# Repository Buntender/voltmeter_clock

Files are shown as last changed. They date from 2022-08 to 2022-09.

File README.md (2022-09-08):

# TimeCube

## 材料

esp8266开发板、5v电压表（6C2型）、电阻、杜邦线、Micro USB延长线、绝缘胶带、胶水、角码、螺丝螺母

螺丝刀 手钻 电烙铁

<div align=center>
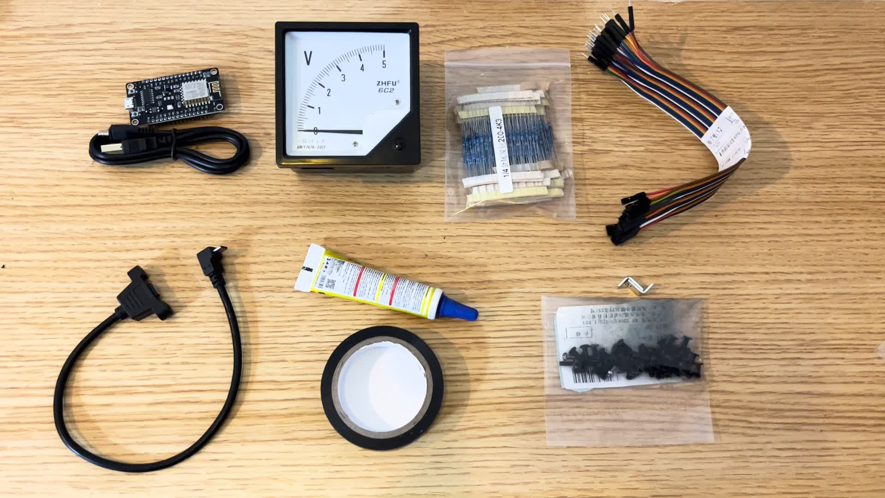
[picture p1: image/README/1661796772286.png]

</div>

## 获取网络时间

配网部分参考了[https://github.com/yuan910715/Esp8266_NTP_Clock_Weather](https://github.com/yuan910715/Esp8266_NTP_Clock_Weather)

开机后首先进入STA模式，通过wificonnect.h中的WIFI_STA,WIFI_PWD连接wifi，连接失败则进入AP模式，用电脑连接热点TimeCube，访问[http://192.168.4.1](http://192.168.4.1/)即可配网。联网成功后通过NTP获取时间。

烧写timetest即可从网络获取时间并经串口发出。

<div align=center>
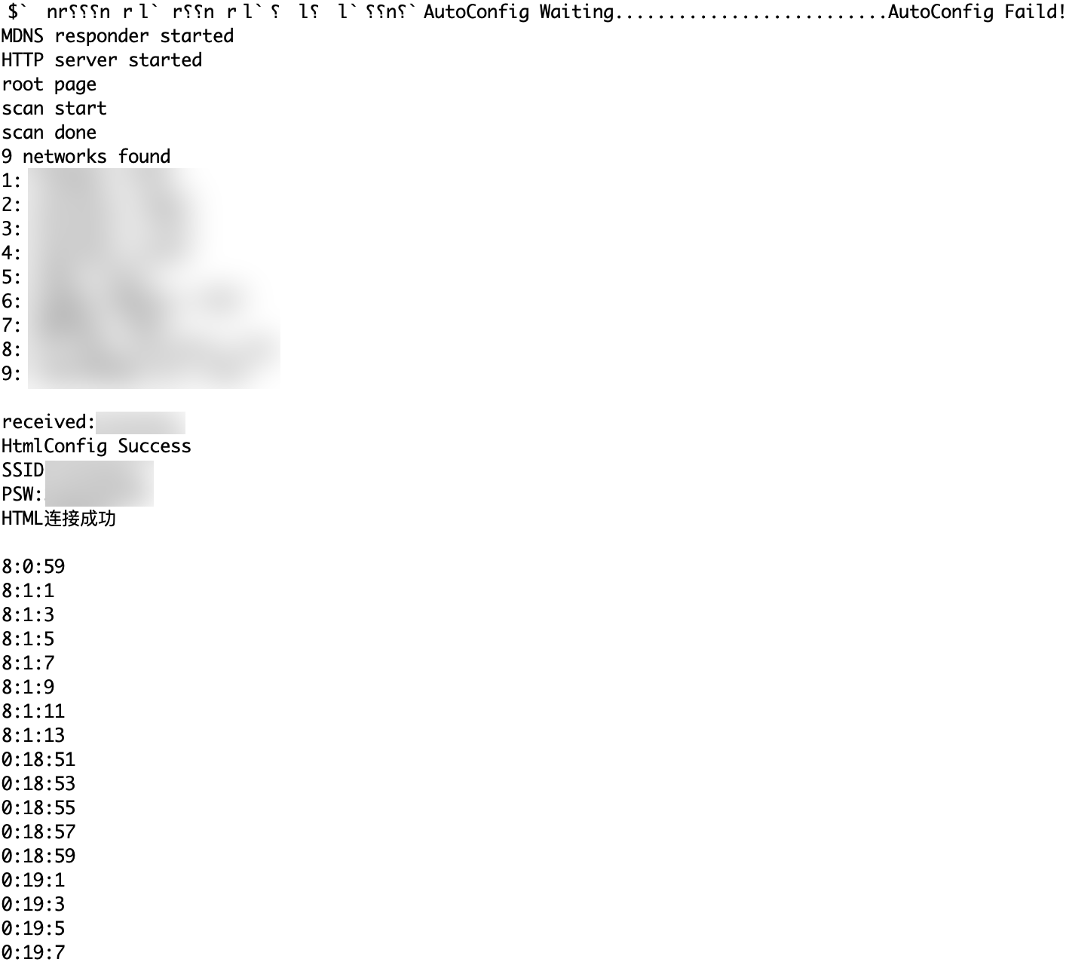
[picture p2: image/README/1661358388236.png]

</div>

可以注意到，设置NTP服务器后，程序会在后台同步时间（如不能同步可以在configTime更换其他国内NTP服务器地址）。

## PWM控制电压表

选择具有PWM输出功能的GPIO口，连接电压表，调整metertest中的METER引脚为相应端口并烧入，可以看到指针匀速划过表盘，但不能划过整个表盘，这是因为ESP8266的工作电压是3.3v，小于电压表的最大值。

<div align=center>
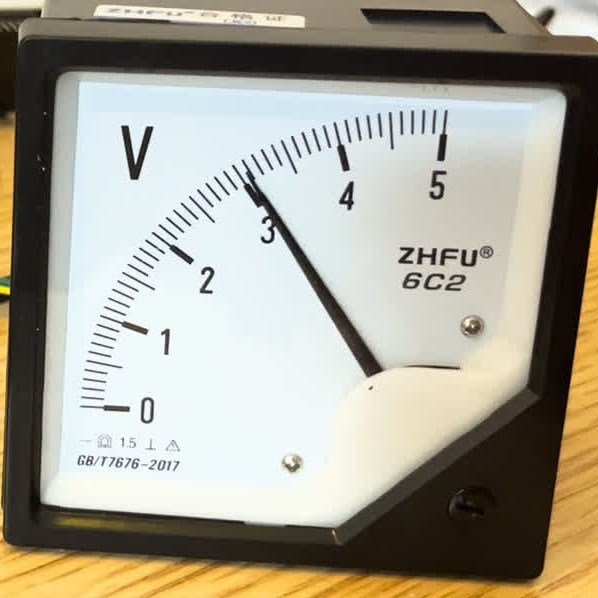
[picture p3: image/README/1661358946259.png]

</div>

拆开电压表后可以看到电压表的结构为表头串联3.3k电阻，则调整量程至3.3v所需的电阻大小为

<div align=center>
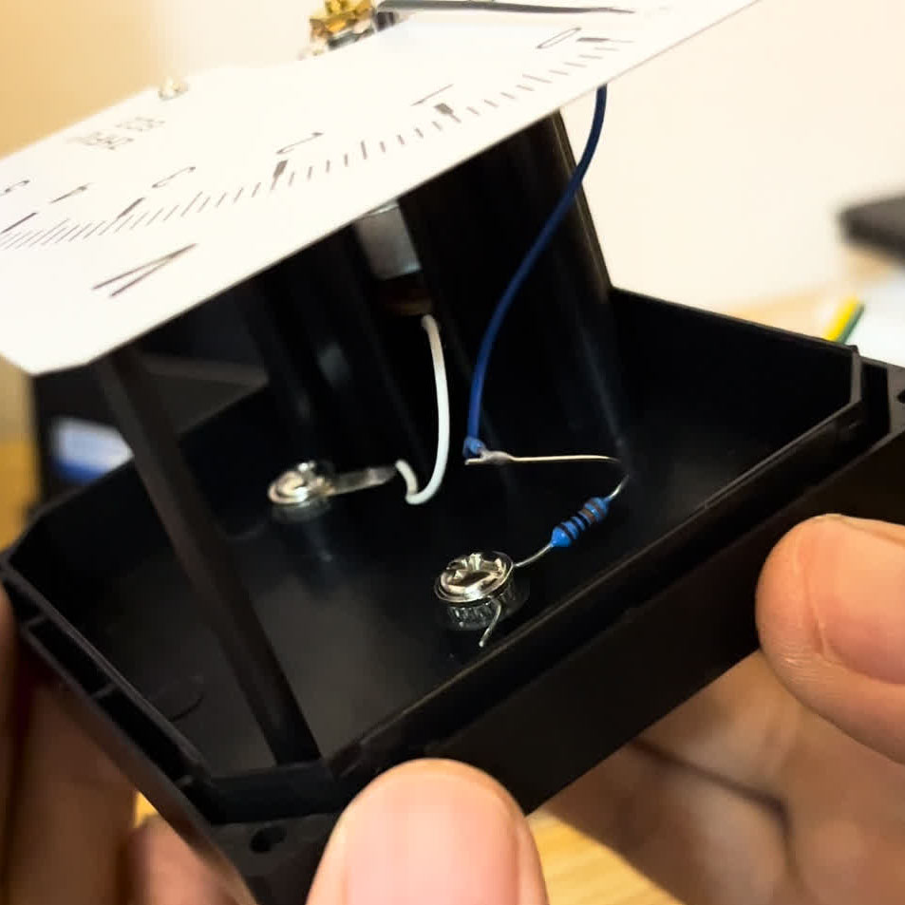
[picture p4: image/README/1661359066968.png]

</div>

$$
\frac{3.3k\Omega}{5v}\times 3.3v\approx2.2k\Omega
$$

为保证指针可以达到满偏（如超过可以在程序中调整最大电压），这里选择阻值为2k的电阻。

<div align=center>
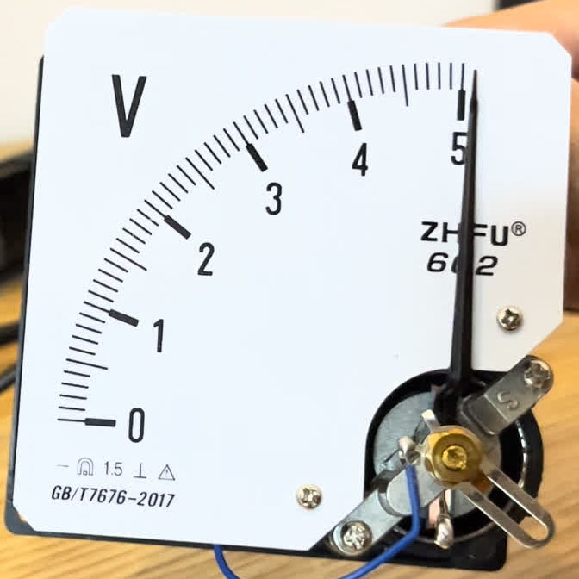
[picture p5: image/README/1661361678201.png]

</div>

最后在表盘黏贴新的刻度即完成了电流表的改装，表盘的设计可以参考panel.ai(panel.png)其中红色的部分需要裁去。

<div align=center>

</div>

## 程序实现

表头时钟TimeCube程序是基于timetest与metertest实现的（如果在ntptest与metertest中调整了参数需要拷贝至TimeCube中），为增强可用性做了一些修改。

* 为防止指针突然运动，在惯性的作用下超出量程打弯指针，也是为了运行中的美观，程序不应突然改变电压。常规走时时，通过循环与延时逐渐改变；归零时（从11点59分到0点）先将电压降为0让指针加速回落，再在指针即将归零前升高电压令指针减速。停止部分的参数和电压表有关，需自行调整，手机的慢动作摄影可以帮助确认减速的时机。

<div align=center>

</div>

* SSID和密码保存在EEPROM中，手动配网时更新保存的密码，重启后不需要重新配网。这一部分参考了[https://blog.csdn.net/qq_31878883/article/details/121452667](https://blog.csdn.net/qq_31878883/article/details/121452667https://blog.csdn.net/qq_31878883/article/details/121452667)
* NTP同步在后台运行，通过系统时间的大小判断是否同步成功（同步后时间在2020年后）。若当前时间正确，可在同步前先减去1.5768e9秒（50年），再判断系统时间。
* 配网时扫描指针。
* 为节省电能，时钟每六小时连接一次网络，通过WiFi.forceSleepBegin和WiFi.forceSleepWake实现。若连续7天未同步成功则重启。

## 组装

在背板上打孔固定micro usb延长线与esp8266开发板（开发板是纵向安放的，安装时用到了角码）

<div align=center>
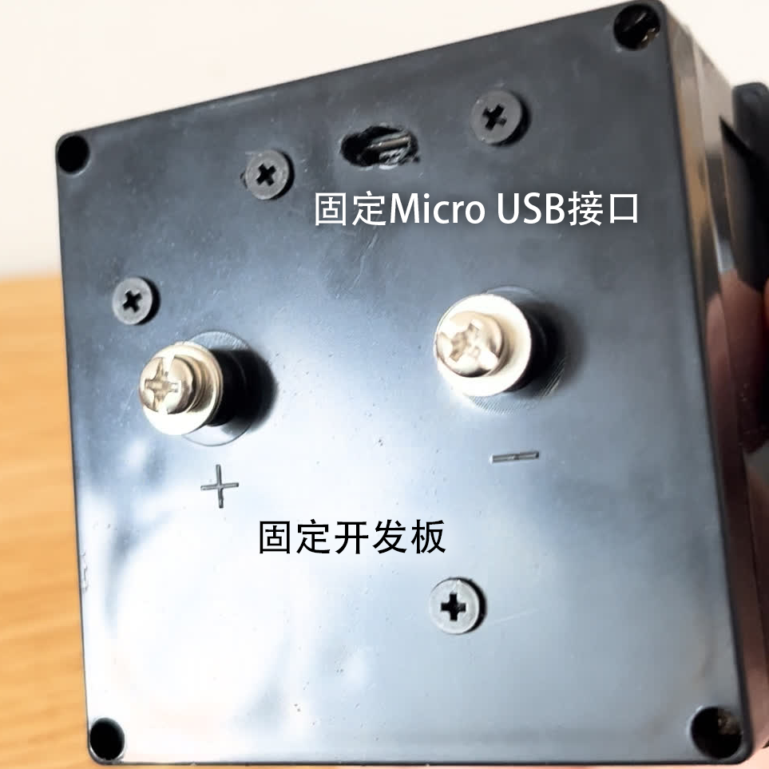
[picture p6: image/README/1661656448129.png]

</div>

分别从接线柱和表头引线用于供电和指示

<div align=center>
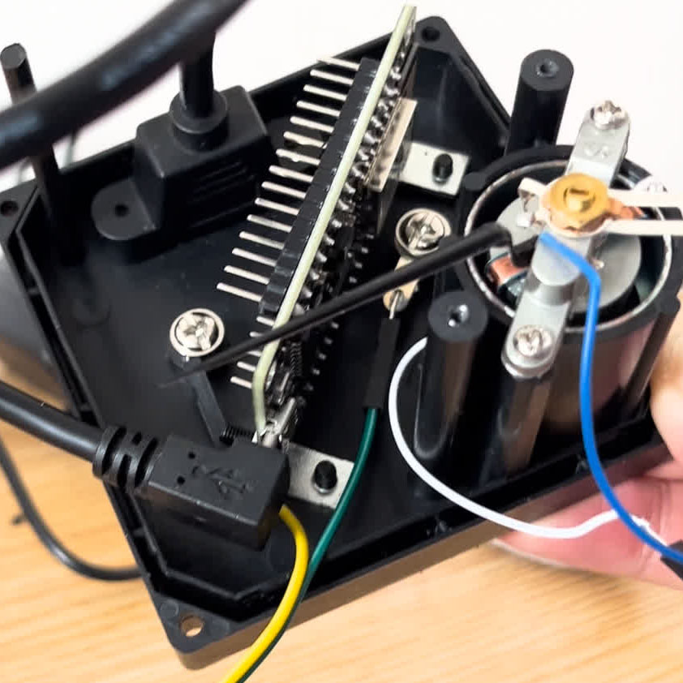
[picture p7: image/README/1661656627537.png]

</div>

完成连线的效果如下，需注意用绝缘胶带覆盖裸露导线，用胶水固定连接处防止脱落

<div align=center>
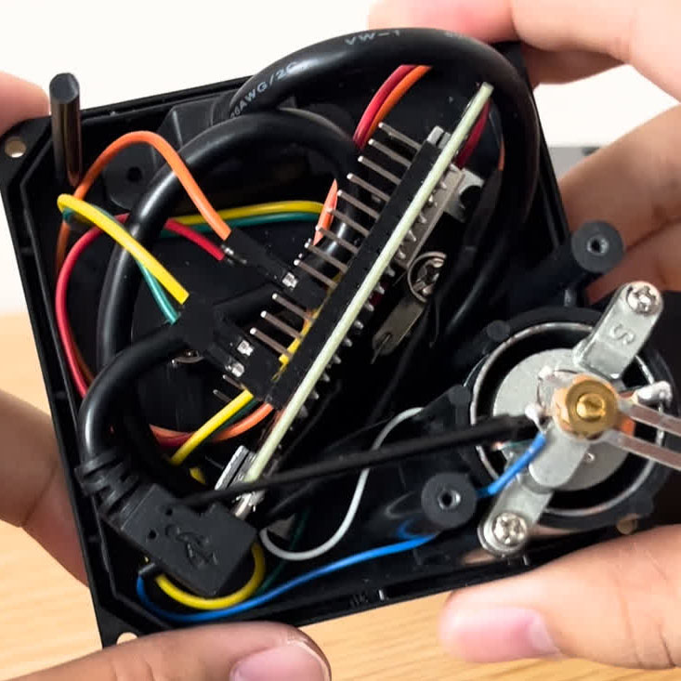
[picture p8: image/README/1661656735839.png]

</div>

实现效果

<div align=center>

</div>

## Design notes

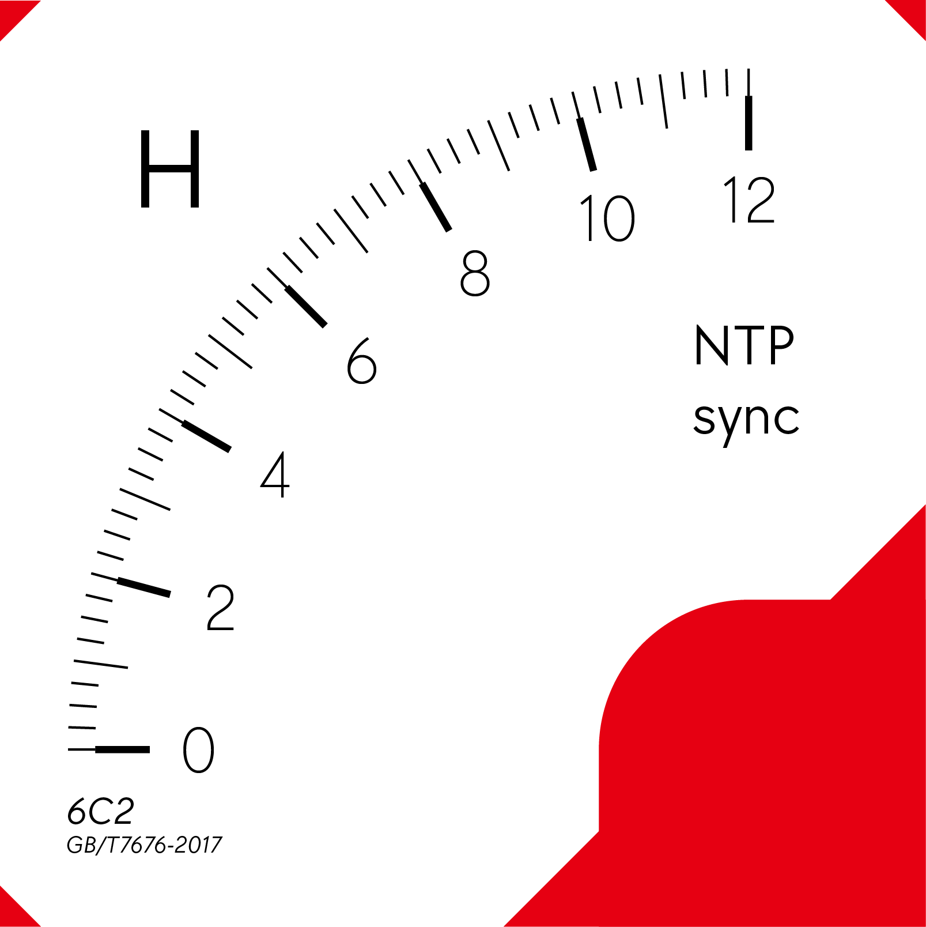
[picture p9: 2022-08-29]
panel.png

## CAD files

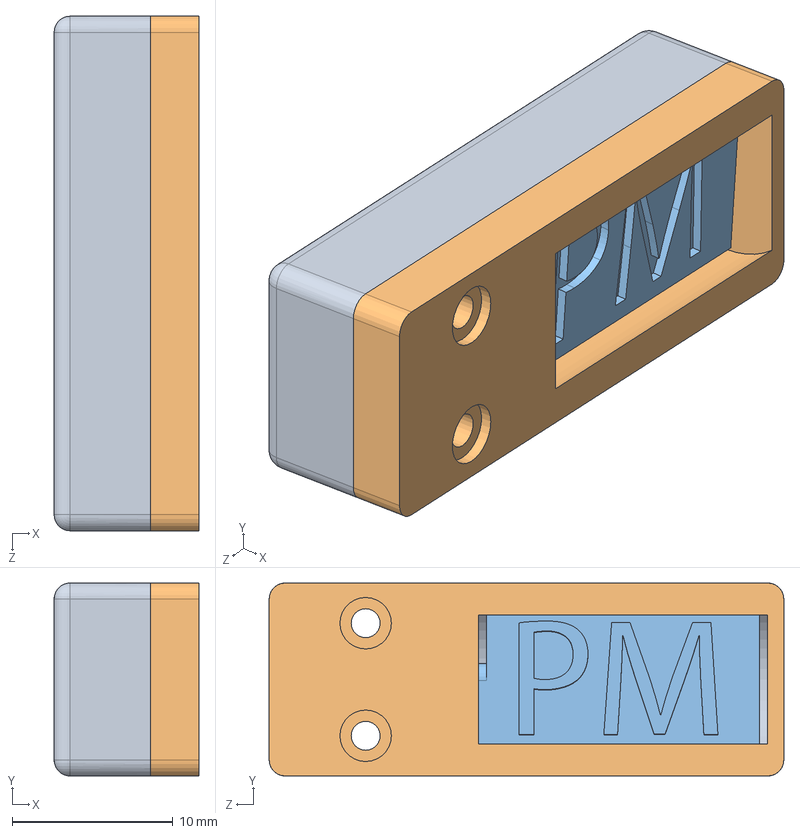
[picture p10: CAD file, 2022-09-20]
flipsign/clockanno.SLDASM
9.00 x 12.0 x 32.0 mm
clockannoback
clockannofront
clockannoflipboard

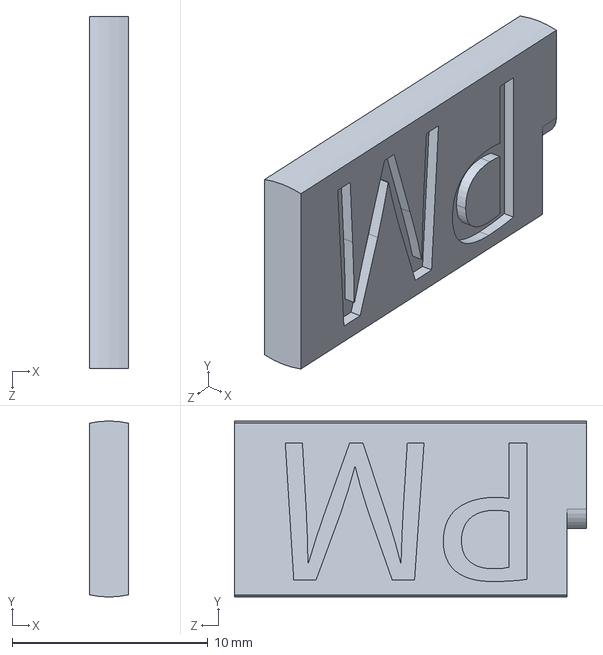
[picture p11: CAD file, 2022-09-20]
flipsign/clockannoflipboard.SLDPRT
2.00 x 9.00 x 18.0 mm

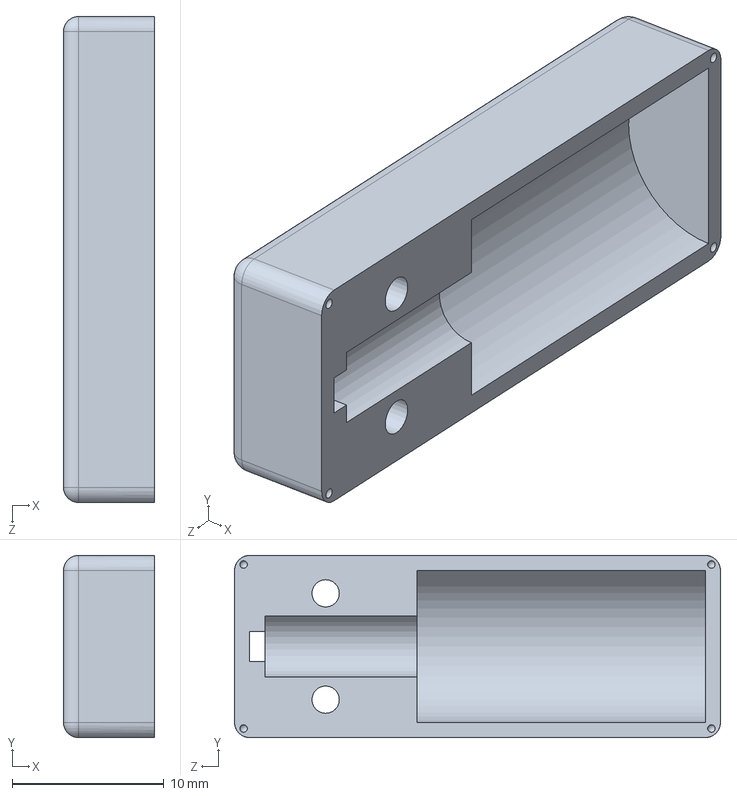
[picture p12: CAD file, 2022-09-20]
flipsign/clockannoback.SLDPRT
6.00 x 12.0 x 32.0 mm

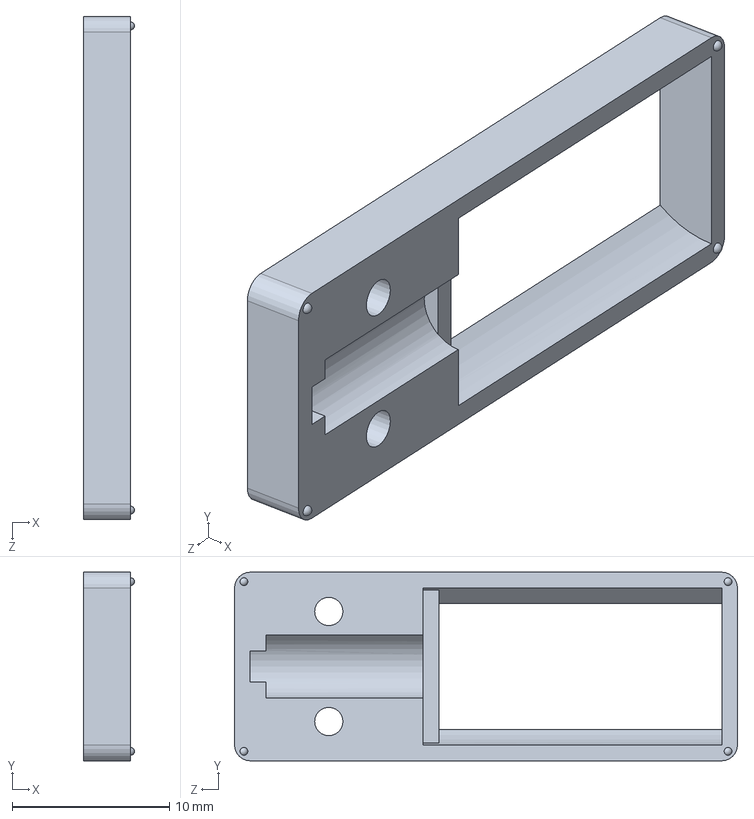
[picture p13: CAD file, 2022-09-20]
flipsign/clockannofront.SLDPRT
3.25 x 12.0 x 32.0 mm

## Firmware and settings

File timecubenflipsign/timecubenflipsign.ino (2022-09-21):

#include <Arduino.h>

// time
#include <time.h>                       // time() ctime()
#include <sys/time.h>                   // struct timeval
#include <coredecls.h>                  // settimeofday_cb()

#include "wificonnect.h"
#include "meter.h"

#include "Ticker.h"

/***************************
 * Begin Settings
 **************************/

#define TZ              8       // (utc+) TZ in hours
#define DST_MN          0      // use 60mn for summer time in some countries

/***************************
 * End Settings
 **************************/

#define TZ_MN           ((TZ)*60)
#define TZ_SEC          ((TZ)*3600)
#define DST_SEC         ((DST_MN)*60)

#define VALIDTIME(TIME) (TIME > 1576800000)
#define GETINVALIDTIME(TIME) (TIME - 1576800000)

long timeSinceLastWUpdate = 0;
long timeSinceLastCurrUpdate = 0;

uint8_t METER_PIN = 4, SIGN_POS = 15, SIGN_NEG = 13;
meter* mymeter;

int getLocalTime()
{
  time_t now;
  time(&now);
  struct tm * timeinfo;
  timeinfo = localtime(&now);
  Serial.print(timeinfo->tm_hour);
  Serial.print(":");
  Serial.println(timeinfo->tm_min);
  return timeinfo->tm_hour * 60 + timeinfo->tm_min;
}

void setup() {
  Serial.begin(115200);
  mymeter = new meter(METER_PIN, SIGN_POS, SIGN_NEG);
  
  auto stepforwardwrapper = []() -> void {mymeter->stepforward();};
  Ticker scanpin;
  scanpin.attach_ms(20, stepforwardwrapper);

  while(!VALIDTIME(time(nullptr))){
    WiFi.mode(WIFI_OFF);
    if(lastConfig() == false){
      htmlConfig();//HTML配网
    }
    Serial.println("");
    configTime(TZ_SEC, DST_SEC, "pool.ntp.org","0.cn.pool.ntp.org","1.cn.pool.ntp.org");
    for(int timeout = 600; timeout > 0; timeout--){
        if(VALIDTIME(time(nullptr))) break;
        delay(500);
        Serial.print(".");
    }
  }
  
  WiFi.forceSleepBegin(); // Wifi off
}

void loop() {
  static int reliability = 28;
  int curtime = getLocalTime();
  mymeter->trans(curtime);
  if (curtime % 360 <= 355 && curtime % 360 >= 354) {
    WiFi.forceSleepWake(); // Wifi on
    yield();
    lastConfig();
    if(VALIDTIME(time(nullptr))){
      time_t rtc = GETINVALIDTIME(time(nullptr));
      timeval tv = { rtc, 0 };
      settimeofday(&tv, nullptr);
    }
    
    configTime(TZ_SEC, DST_SEC, "pool.ntp.org","0.cn.pool.ntp.org","1.cn.pool.ntp.org");
    for(int timeout = 600; timeout > 0; timeout--){
        if(VALIDTIME(time(nullptr))) break;
        delay(500);
        Serial.print(".");
    }
    if(!VALIDTIME(time(nullptr))) reliability--;
    else reliability = 28;
    if(reliability <= 0) ESP.restart();
    WiFi.forceSleepBegin(); // Wifi off
  }
  if (curtime % 720 < 718) delay(60 * 1000);
  else delay(1000);
}

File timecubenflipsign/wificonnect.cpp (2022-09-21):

#include "wificonnect.h"

ESP8266WebServer server(80);

bool lastConfig()
{
  WiFi.mode(WIFI_STA);
  WifiPwd* wifipwd = loadConfigs();
  if(strlen(wifipwd->pwd) > 0){
    WiFi.begin(wifipwd->ssid, wifipwd->pwd);
    Serial.print("AutoConfig Waiting......");
    for (int i = 0; i < 20; i++)
    {
      if (WiFi.status() == WL_CONNECTED)
      {
        Serial.println("AutoConfig Success");
        Serial.printf("SSID:%s\r\n", WiFi.SSID().c_str());
        Serial.printf("PSW:%s\r\n", WiFi.psk().c_str());
        Serial.print("IP address:");
        Serial.println(WiFi.localIP());
        WiFi.printDiag(Serial);
        delete wifipwd;
        return true;
      }
      else
      {
         delay(500);
         Serial.print(".");
      }
    }
  }
  Serial.println("AutoConfig Faild!" );
  delete wifipwd;
  return false;
}

void handleRoot() {
    Serial.println("root page");
    String str = HTML_TITLE + HTML_SCRIPT_ONE + HTML_SCRIPT_TWO + HTML_HEAD_BODY_BEGIN + HTML_FORM_ONE + HTML_BODY_HTML_END;
    server.send(200, "text/html", str);
}

void HandleScanWifi() {
    Serial.println("scan start");

    String HTML_FORM_TABLE_BEGIN = "<table><head><tr><th>序号</th><th>名称</th><th>强度</th></tr></head><body>";
    String HTML_FORM_TABLE_END = "</body></table>";
    String HTML_FORM_TABLE_CON = "";
    String HTML_TABLE;
    // WiFi.scanNetworks will return the number of networks found
    int n = WiFi.scanNetworks();
    Serial.println("scan done");
    if (n == 0) {
        Serial.println("no networks found");
        HTML_TABLE = "NO WIFI !!!";
    }
    else {
        Serial.print(n);
        Serial.println(" networks found");
        for (int i = 0; i < n; ++i) {
      // Print SSID and RSSI for each network found
            Serial.print(i + 1);
            Serial.print(": ");
            Serial.print(WiFi.SSID(i));
            Serial.print(" (");
            Serial.print(WiFi.RSSI(i));
            Serial.print(")");
            Serial.println((WiFi.encryptionType(i) == ENC_TYPE_NONE) ? " " : "*");
            delay(10);
            HTML_FORM_TABLE_CON = HTML_FORM_TABLE_CON + "<tr><td align=\"center\">" + String(i+1) + "</td><td align=\"center\">" + "<a href='#p' onclick='c(this)'>" + WiFi.SSID(i) + "</a>" + "</td><td align=\"center\">" + WiFi.RSSI(i) + "</td></tr>";
        }

        HTML_TABLE = HTML_FORM_TABLE_BEGIN + HTML_FORM_TABLE_CON + HTML_FORM_TABLE_END;
    }
    Serial.println("");

    String scanstr = HTML_TITLE + HTML_SCRIPT_ONE + HTML_SCRIPT_TWO + HTML_HEAD_BODY_BEGIN + HTML_FORM_ONE + HTML_TABLE + HTML_BODY_HTML_END;

    server.send(200, "text/html", scanstr);
}

void HandleWifi()
{
    String wifis = server.arg("ssid"); //从JavaScript发送的数据中找ssid的值
    String wifip = server.arg("password"); //从JavaScript发送的数据中找password的值
    Serial.println("received:"+wifis);
    server.send(200, "text/html", "连接中..");
    WiFi.begin(wifis,wifip);
}

void handleNotFound() { 
  String message = "File Not Found\n\n";
  message += "URI: ";
  message += server.uri();
  message += "\nMethod: ";
  message += (server.method() == HTTP_GET) ? "GET" : "POST";
  message += "\nArguments: ";
  message += server.args();
  message += "\n";
  for (uint8_t i = 0; i < server.args(); i++) {
    message += " " + server.argName(i) + ": " + server.arg(i) + "\n";
  }
  server.send(404, "text/plain", message);
}

void htmlConfig()
{
    WiFi.mode(WIFI_AP_STA);//设置模式为AP+STA
    WiFi.softAP("TimeCube");

    IPAddress myIP = WiFi.softAPIP();
  
    if (MDNS.begin("clock")) {
      Serial.println("MDNS responder started");
    }
    
    server.on("/", handleRoot);
    server.on("/HandleWifi", HTTP_GET, HandleWifi);
    server.on("/HandleScanWifi", HandleScanWifi);
    server.onNotFound(handleNotFound);//请求失败回调函数
    MDNS.addService("http", "tcp", 80);
    server.begin();//开启服务器
    Serial.println("HTTP server started");
    while(1)
    {
        server.handleClient();
        MDNS.update();  
        delay(500);
        if (WiFi.status() == WL_CONNECTED)
        {
            Serial.println("HtmlConfig Success");
            Serial.printf("SSID:%s\r\n", WiFi.SSID().c_str());
            Serial.printf("PSW:%s\r\n", WiFi.psk().c_str());
            Serial.println("HTML连接成功");
            WifiPwd *wifipwd  = new WifiPwd;
            strcpy(wifipwd->ssid, WiFi.SSID().c_str());
            strcpy(wifipwd->pwd, WiFi.psk().c_str());
            saveConfig(wifipwd);
            break;
        }
    }
    server.close();  
    WiFi.mode(WIFI_STA);   
}
